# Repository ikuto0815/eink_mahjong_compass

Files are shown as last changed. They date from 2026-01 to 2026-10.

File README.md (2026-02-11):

# E-ink mahjong compass

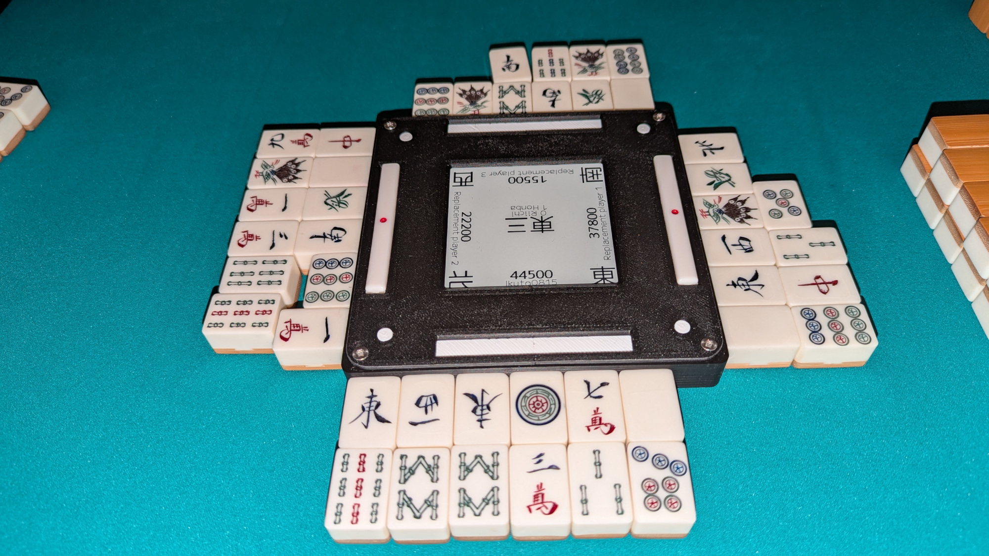
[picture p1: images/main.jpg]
The compass in use


This repo contains all the files neccesary to build a bluetooth controlled digital mahjong compass.

The project is divided into the following main parts:

* [**3d**](3d): the freecad project and stl-files to 3D print the case
* [**android_app**](android_app): the android app used to control the device
* [**firmware**](firmware): firmware for the ESP32 microcontroller inside
* [**pcb**](pcb): design files for the custom PCB

Additional folders:

* [**fontconvert**](fontconvert): tool to convert fonts to C headers, so they can be used in the firmware
* [**hardware**](hardware): datasheets for parts used on the PCB

## PCB

The custom made PCB contains an ESP32-S3-WROOM1 microcontroller to talk to a phone via bluetooth and control the connected periphery.

It has the following components:

* 4.2 inch 400x300 (300x300 visible) E-ink display
* 4 buttons for controlling the device
* 4 indicator LEDs placed below the riichi bet trays of each player
* USB-C port for programming the ESP32 and charging the battery
* TP4056 module to control charging of a single cell LiPo battery via the USB-C port
* (optional and untested MAX17048 fuel gauge controller to determine the battery charge)

The production subfolder contains all the files needed to order the PCBs.
The `eink_mahjong_compass.zip` file contains alle the gerber files needed to order the PCB.
`bom.csv` and `positions.csv` are additionally needed when ordering the PCBs assembled.
The files for assembly will work for JLCPCB, other sites might need a different file format.

Even when ordering with assembly, two parts have to be soldered by hand. Those being the connector
for the E-ink display and the ESP32 module. Adding those would make the assembly service much more expensive.

## How to build

### Requirements

The following things need to be ordered:

* WeAct 4.2 inch Epaper module <https://aliexpress.com/item/1005008461198386.html> (only sold by WeAct Studio Official Store, order the black/white one, the black/red/white variant might not work)
* ESP32-S3-WROOM1-N4 <https://aliexpress.com/item/1005004815894336.html> (there are various vendors, they should all be fine. -N4 is the cheapest variant with 4MB flash and no external RAM. The better variants will probably work as well but won't provide any benefits)
* 2x 4 pin PCB Female Pin Header Socket Connector <https://aliexpress.com/item/1005004122312694.html> for the display connector
* (optional) Ntag 215 NFC tag stickers <https://aliexpress.com/item/1005006387440192.html> stick them on the underside of the lid and write the connect URL to them, so the app auto starts when touching item
* battery, either a 5000mAh 105080 or a 6000mAh 906090 can be used, other formats would need changes to the 3D printed part to hold the battery in place. Example seller <https://aliexpress.com/item/1005004639603622.html> batteries from other sellers will probably work fine as well, but a 2 pin connector is required, not a 3 pin one.
* M3xL4xOD4.2 brass insert nuts. <https://de.aliexpress.com/item/1005006472702418.html> Molded into the case to hold the lid screws
* M3 6mm countersunk screws <https://aliexpress.com/item/33006942612.html>

### Assembly

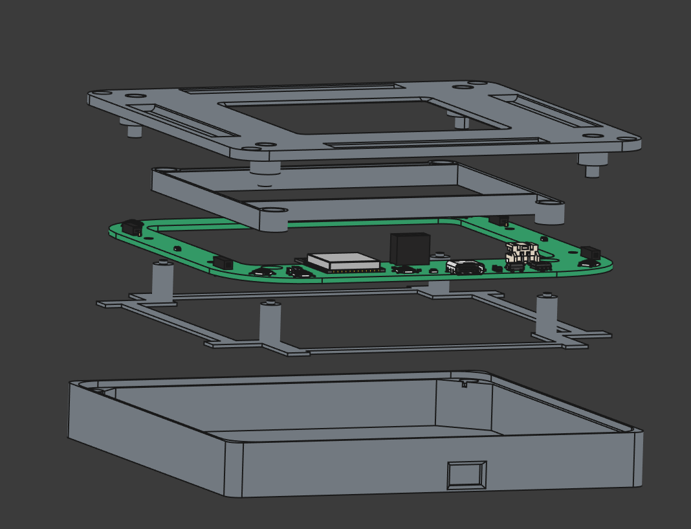
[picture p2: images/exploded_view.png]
exploded view


* 3D print the parts as described in [3d/README](3d/README.md).
* Using a soldering iron push the brass insert nuts into the corners of the case.
* Place the PCB on the printed `display_feet`
* Place the display_feet on top
* Put them into the case
* Place the battery inside and connect it after checking if the polarity of the connector matches that on the PCB.
* Add the screen
* Place the lid on top and screw it down.

### Flashing the firmware

To build and flash the firmware, you need to download and install  [PlatformIO](https://platformio.org/).

Then just connect the compass via USB and run `pio run --target upload` in the firmware directory.

## Other stuff

### Bluetooth interface

The compass currently offers a single BLE service under the UID `bae5e4dd-f2b4-4461-a84c-b7851fb8efd3` with the following characteristics:

#### game state (`bab40271-33ea-48dc-a145-638361f54d2b`)

This characteristic is write only and takes a multi line string that describes the current game state in the following format:

``` text
roundIndex riichiCount honbaCount
windIndex0
score0
name0
windIndex1
score1
name1
windIndex2
score2
name2
windIndex3
score3
name3
```

roundIndex describes the current round of the game (0=E1, 1=E2, 4=S1,...). riichiCount and honbaCount are the number of sticks that would be on the table.

The next lines describe describe the 4 players in the game.
windIndexN is the current wind of each player (0=E, 1=S, 2=W, 3=N).
scoreN and nameN are the current score and name of each player.

The players are drawn on the display in the same order as in the transferred data.

Example:

``` text
1 2 1
0
29000
name0
1
29000
name1
2
38000
name2
3
22000
name3
```

This game is in round east-2, There are two riichi sticks and one honba in the table. Player "name0" is currently east with 29000 points.

#### battery voltage (`bab40271-33ea-48dc-a145-638361f54d2c`)

This characteristic is read-only. It returns the current battery voltage in mV. This can be used for a battery level indicator in the app.

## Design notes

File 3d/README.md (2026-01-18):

This folder contains the 3D models for the case. compass_square.FCStd is the freecad project containing everything.

In the stl folder are stl files for the individual parts that can be directly used for 3D printing.

The files `case.stl`, `display_feet.stl`, `lid.stl` each have to be printed once.

To keep the battery in place either `battery_frame_500mah.stl` (105080 LiPo) or `battery_frame_600mah.stl` (906090 LiPo) can be used. For other battery formats either that part has to be modified or the battery could just be glued to the case.

The parts `button_holder.stl` and `button.stl` each have to be printed 4 times and then glued to the botton of the lid.

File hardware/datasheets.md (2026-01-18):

# Datasheets for used parts

* Battery charging IC TP4056-42-ESOP8
  <https://www.lcsc.com/datasheet/C16581.pdf>
* 3.3V LDO ME6211C33R5G
  <https://www.lcsc.com/datasheet/C235316.pdf>
* USB ESD protection diode SRV05-4-P-T7
  <https://www.lcsc.com/datasheet/C85364.pdf>
* 32.768kHz crystal Q13FC13500004
  <https://www.lcsc.com/datasheet/C32346.pdf>
* P-Channel MOSFET SI2301CDS-T1-GE3
  <https://www.lcsc.com/datasheet/C10487.pdf>
* Schottky diode SS34
  <https://www.lcsc.com/datasheet/C8678.pdf>

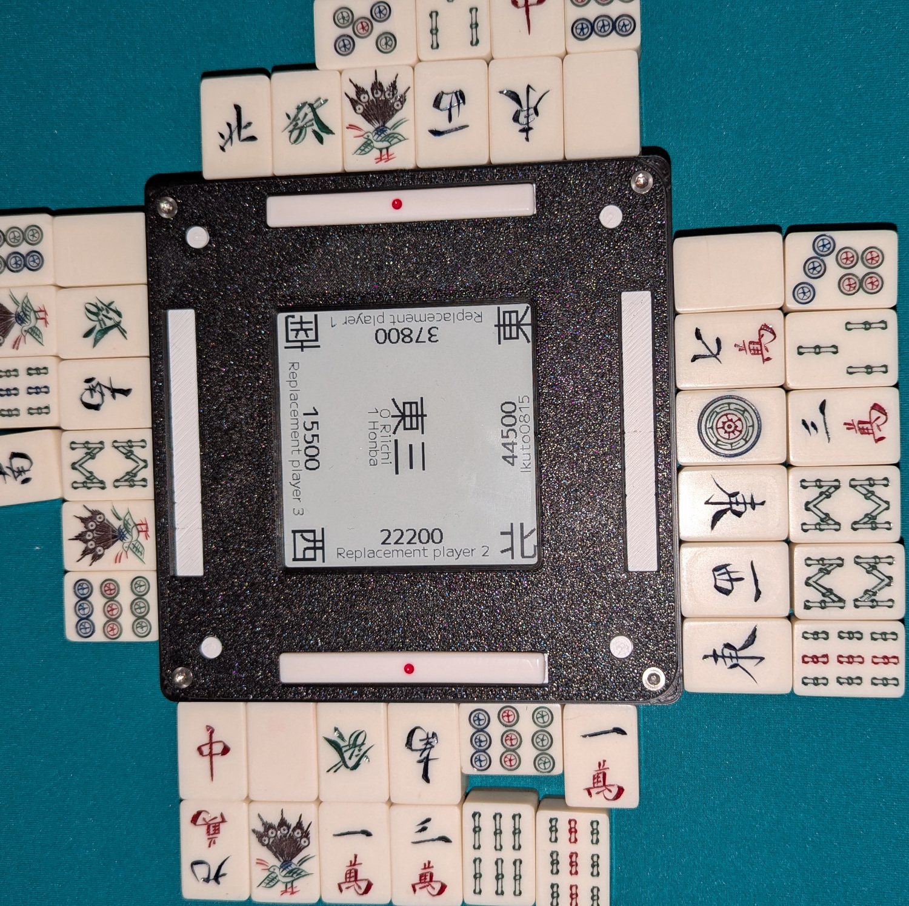
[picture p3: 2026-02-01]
images/top.jpg

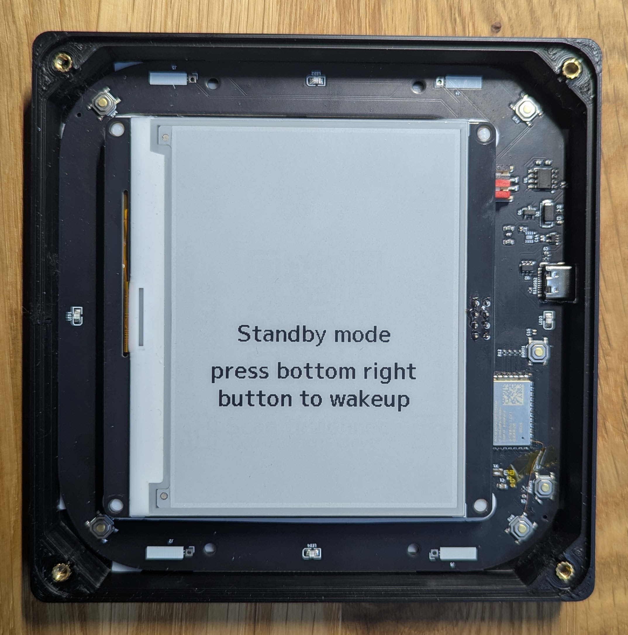
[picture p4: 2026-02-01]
images/inside.jpg

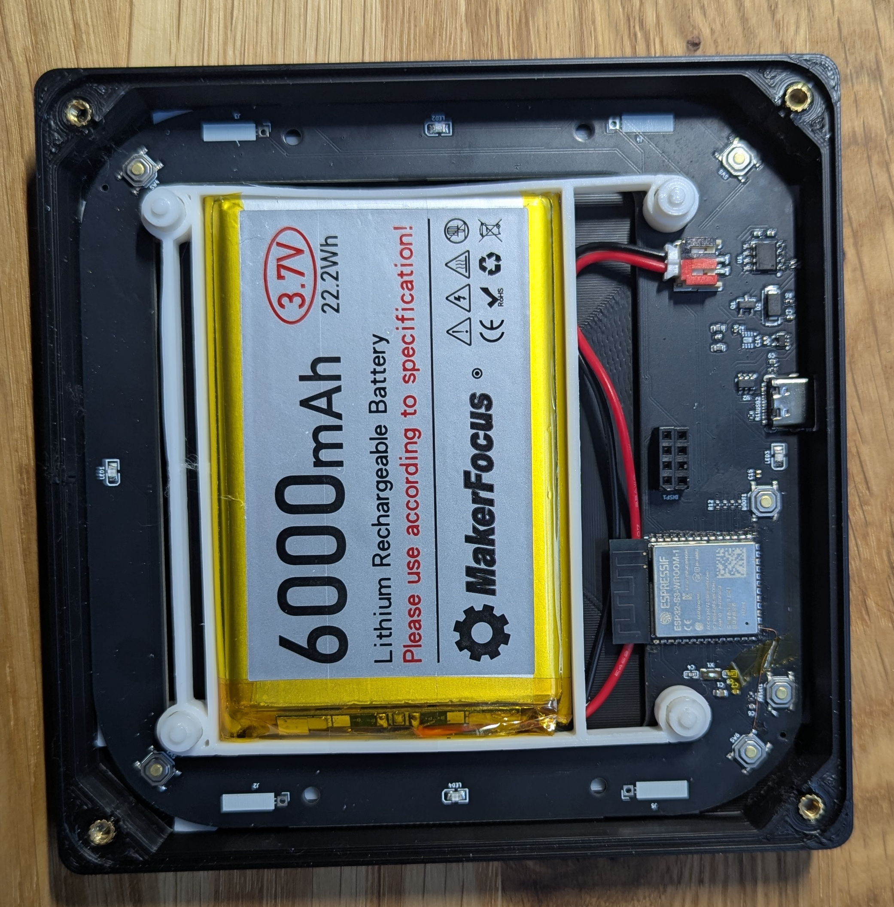
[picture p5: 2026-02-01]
images/inside_2.jpg

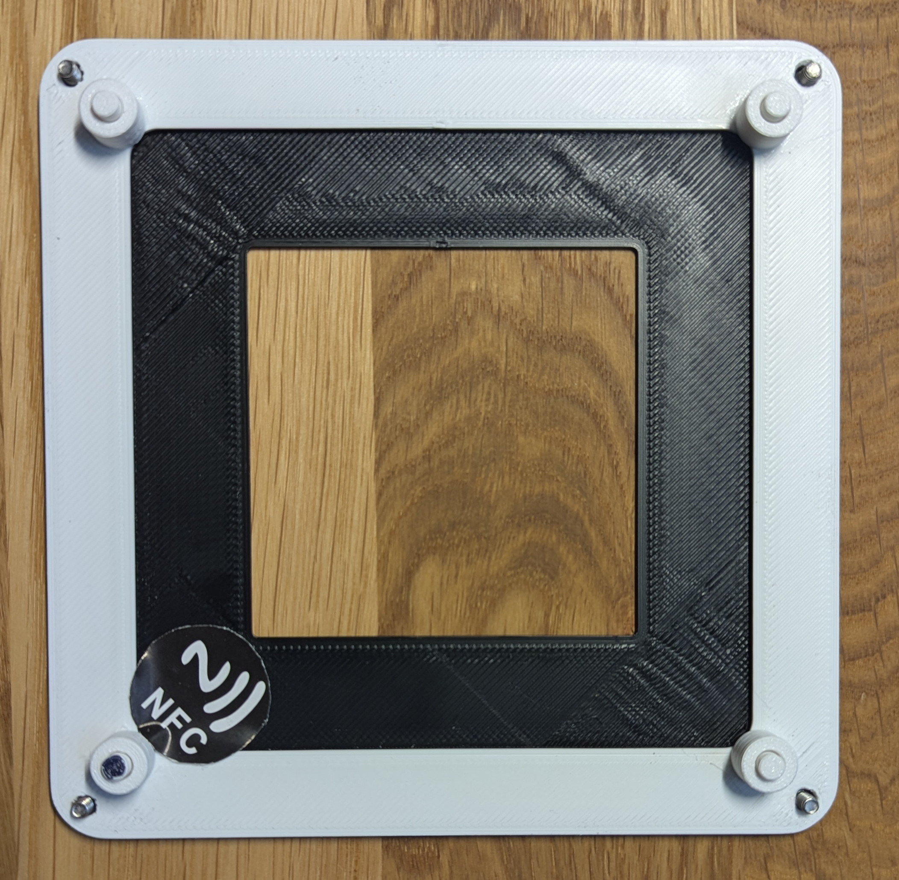
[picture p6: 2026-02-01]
images/lid_underside.jpg

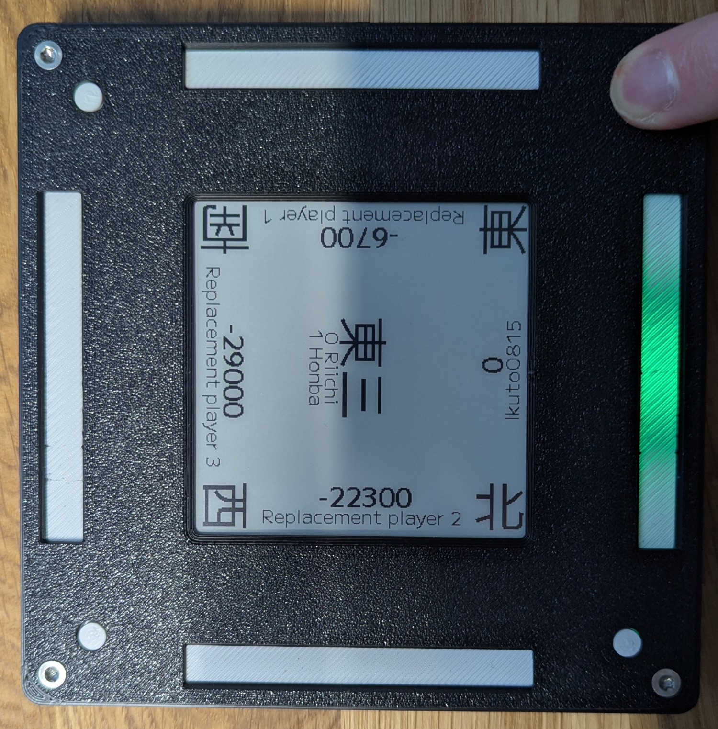
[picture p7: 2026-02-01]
images/button.jpg

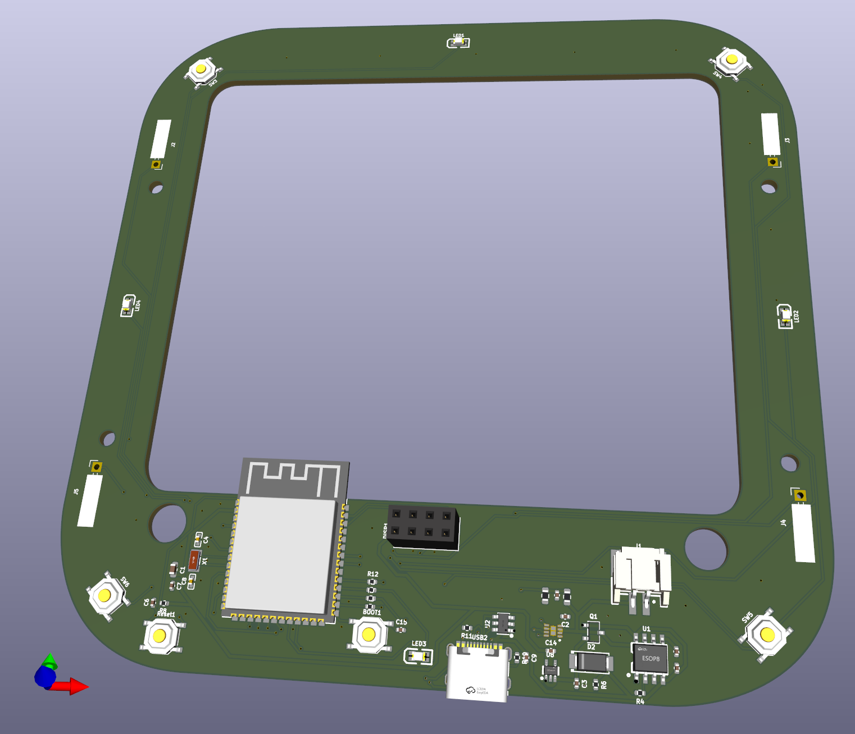
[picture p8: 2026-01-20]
pcb/eink_mahjong_compass.png

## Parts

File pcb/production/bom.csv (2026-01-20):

Designator | Footprint | Quantity | Value | LCSC Part #
BOOT1, RESET1, SW3, SW4, SW5, SW6 | SW-SMD_4P-L5.1-W5.1-P3.70-LS6.5-TL_H1.5 | 6 | C318884
C1 | 0603 | 1 | 22uF
C13, C16 | 0402 | 2 | 10uF
C14, C3 | 0402 | 2 | 1uF
C15, C6 | 0402 | 2 | 1.0uF
C2, C5 | 0402 | 2 | 0.1uF
C4, C8 | C0402 | 2 | 15pF
C7, C9 | 0402 | 2 | 4.7uF
D2 | SMA_L4.3-W2.6-LS5.2-RD | 1 | C8678
DISP1 | PinSocket_2x04_P2.54mm_Vertical | 1 | Conn_02x04_Counter_Clockwise
J1 | CONN-SMD_PH-2AWT | 1 | PH-2AWT | C2763693
LED1, LED2, LED3, LED4 | LED0805-R-RD | 4 | C2297
Q1 | SOT-23-3_L3.0-W1.7-P0.95-LS2.9-BR | 1 | C10487
R1 | 0603 | 1 | 1M
R10, R11 | 0402 | 2 | 5.1k
R12, R5, R7, R9 | 0402 | 4 | 49.9
R2 | 0603 | 1 | 330k
R4 | 0402 | 1 | 2.0k
R6 | 0402 | 1 | 100k
R8 | 0402 | 1 | 10k
U1 | ESOP-8_L4.9-W3.9-P1.27-LS6.0-BL-EP | 1 | C16581
U2 | SOT-23-6_L2.9-W1.6-P0.95-LS2.9-BL | 1 | C85364
U8 | SOT-353_L2.1-W1.3-P0.65-LS2.3-BL | 1 | C235316
USB2 | USB-C_SMD-TYPE-C-31-M-12 | 1 | C2927038
X1 | FC-135R_L3.2-W1.5 | 1 | C32346

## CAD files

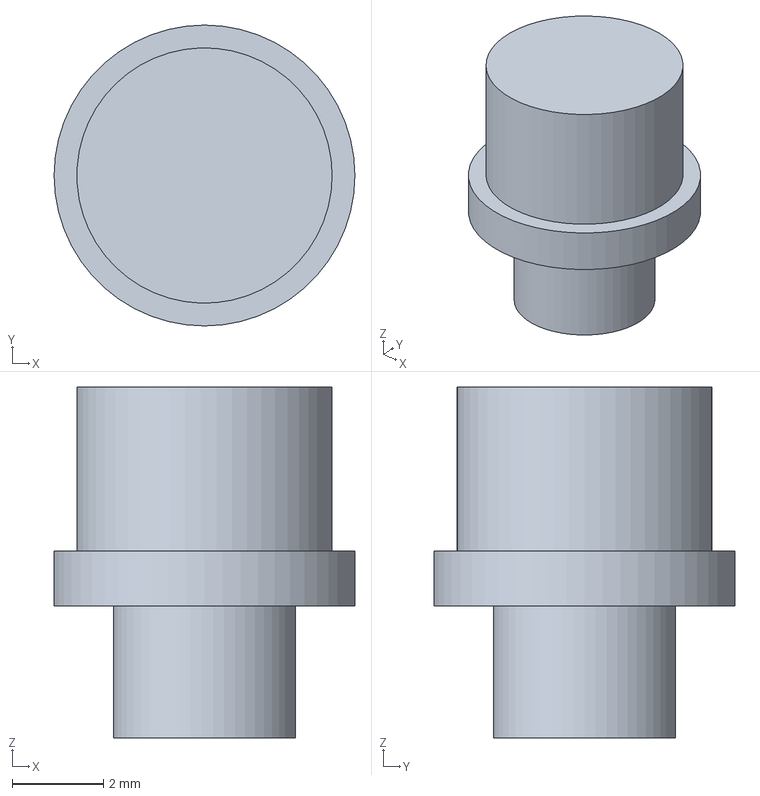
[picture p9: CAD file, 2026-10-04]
3d/compass_square.FCStd
6.60 x 6.60 x 7.70 mm

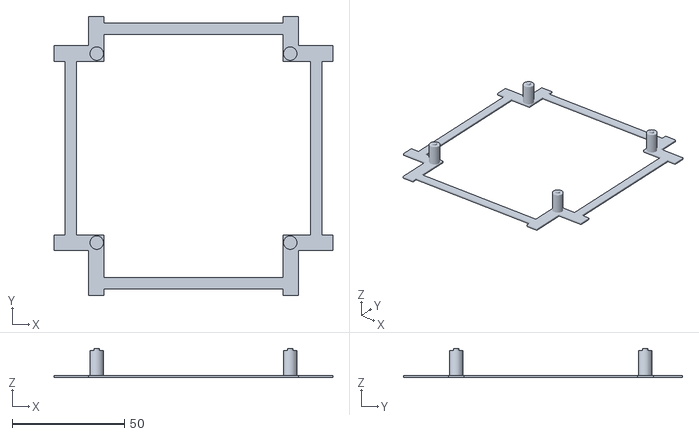
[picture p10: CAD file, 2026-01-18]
3d/stl/display_feet.stl
124.3 x 124.3 x 13.0

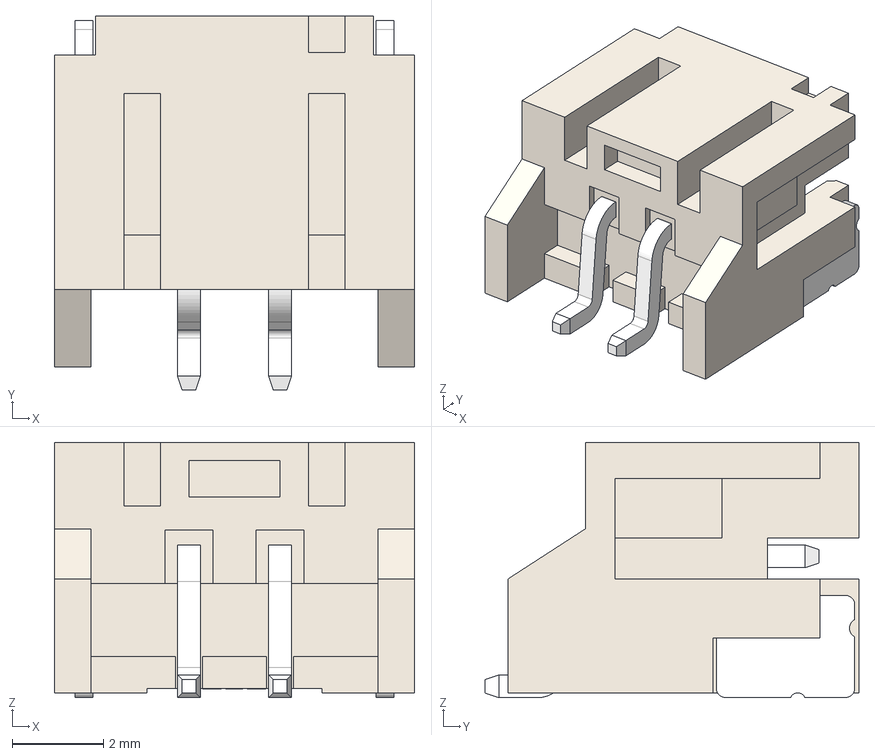
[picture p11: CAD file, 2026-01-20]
pcb/EASYEDA_MODELS/CONN-SMD_PH-2AWT.step
7.90 x 8.20 x 5.61 mm

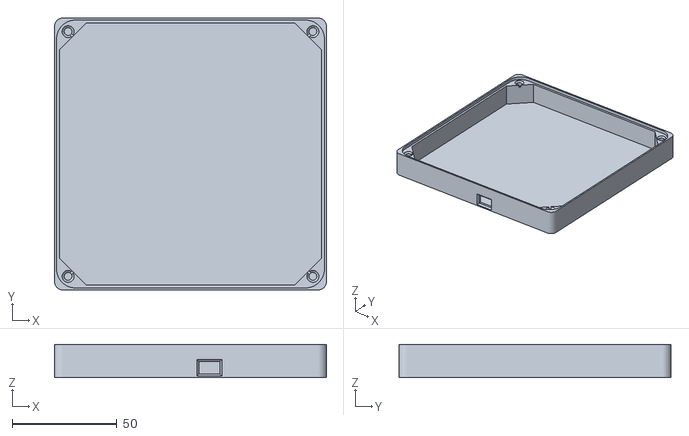
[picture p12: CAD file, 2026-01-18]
3d/stl/case.stl
130.0 x 130.0 x 16.0

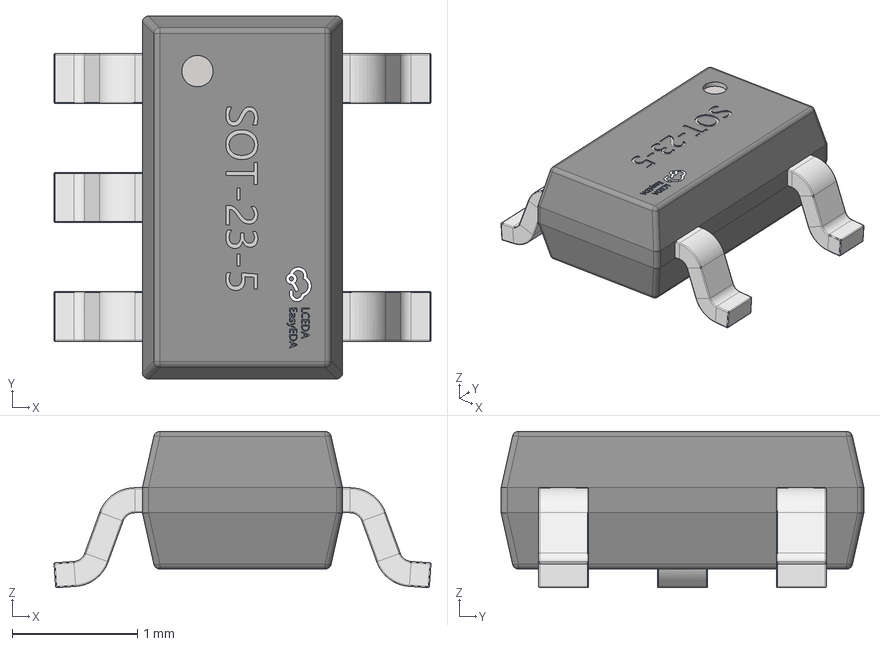
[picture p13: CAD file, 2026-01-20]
pcb/EASYEDA_MODELS/SOT-23-5_L2.9-W1.6-H1.1-LS2.8-P0.95.step
3.01 x 2.90 x 1.25 mm

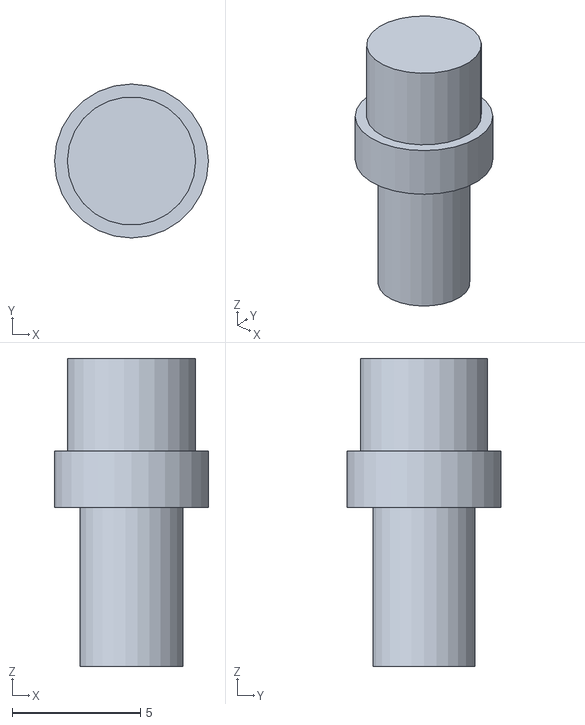
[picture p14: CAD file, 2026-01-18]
3d/stl/button.stl
6.00 x 6.00 x 12.0

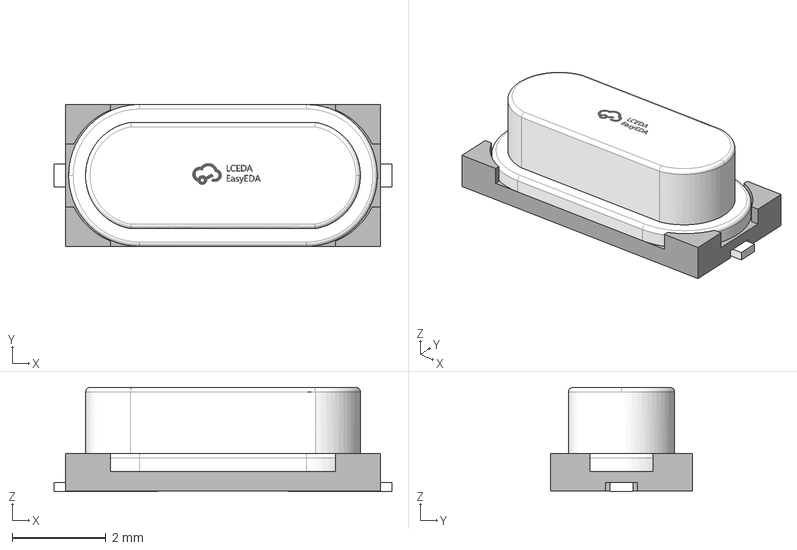
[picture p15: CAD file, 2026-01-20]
pcb/EASYEDA_MODELS/OSC-SMD_L7.0-W3.2-LS7.5.step
7.21 x 3.03 x 2.22 mm

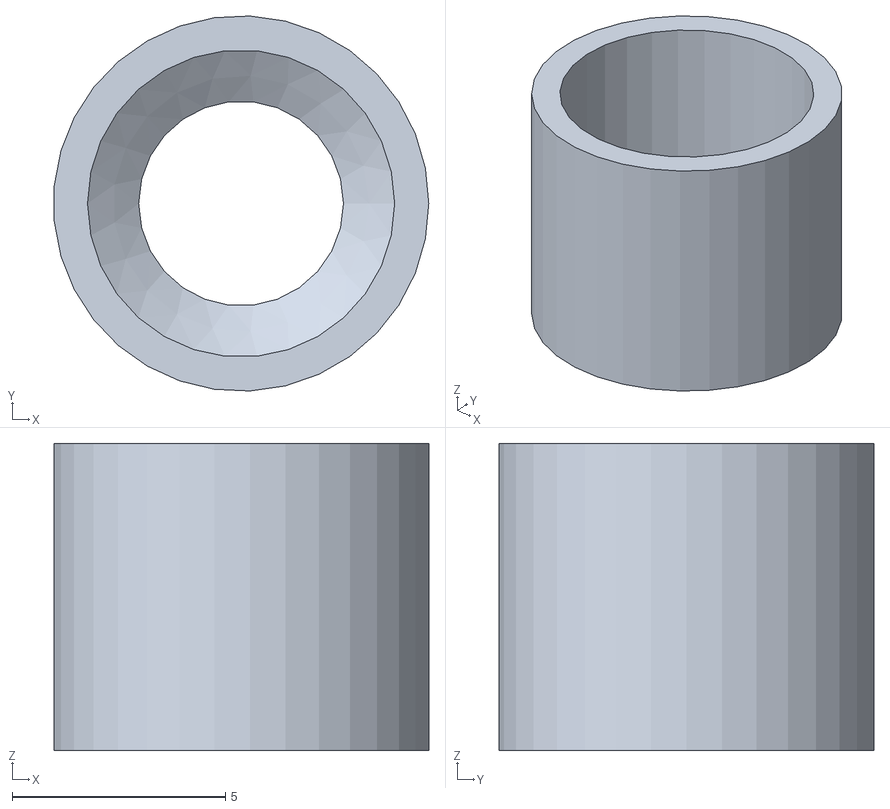
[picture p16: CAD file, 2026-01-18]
3d/stl/button_holder.stl
8.78 x 8.79 x 7.20

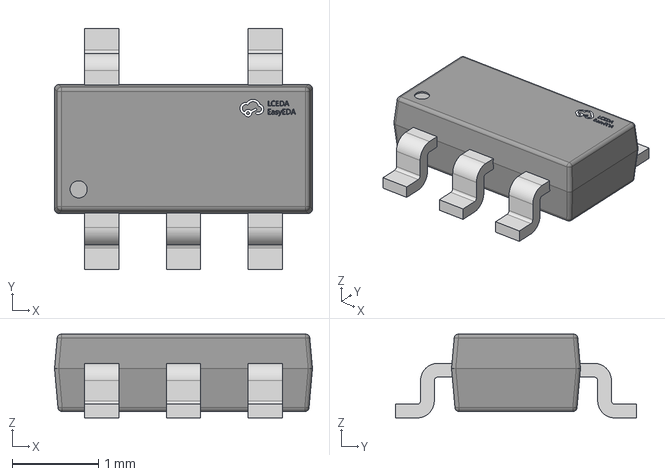
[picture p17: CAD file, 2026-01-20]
pcb/EASYEDA_MODELS/SOT-23-5_L3.0-W1.5-P0.95-LS2.8-BL.step
3.00 x 2.80 x 0.976 mm

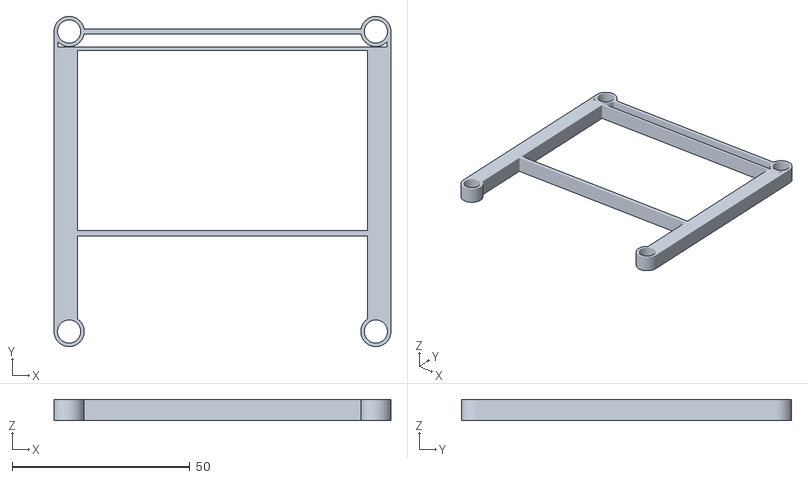
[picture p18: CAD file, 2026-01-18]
3d/stl/battery_frame_500mah.stl
94.7 x 92.8 x 6.00

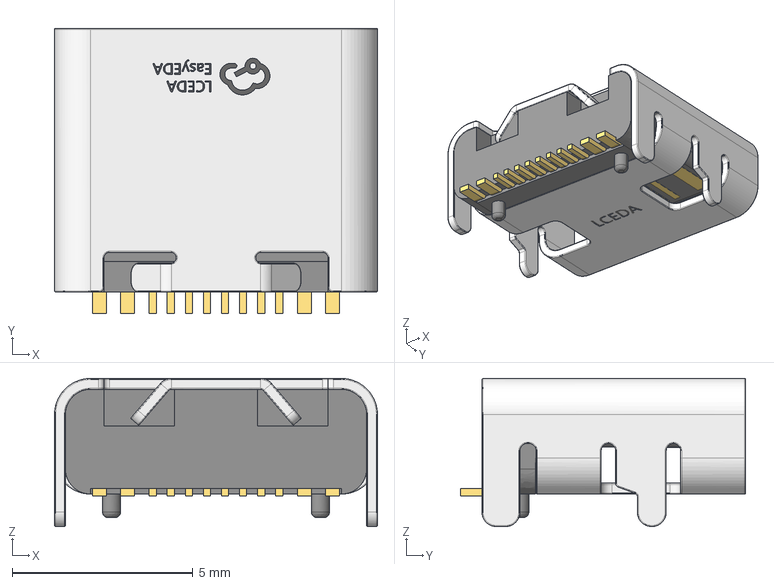
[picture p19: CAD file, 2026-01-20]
pcb/EASYEDA_MODELS/USB-C_SMD-TYPE-C-31-M-12.step
8.94 x 7.90 x 4.10 mm

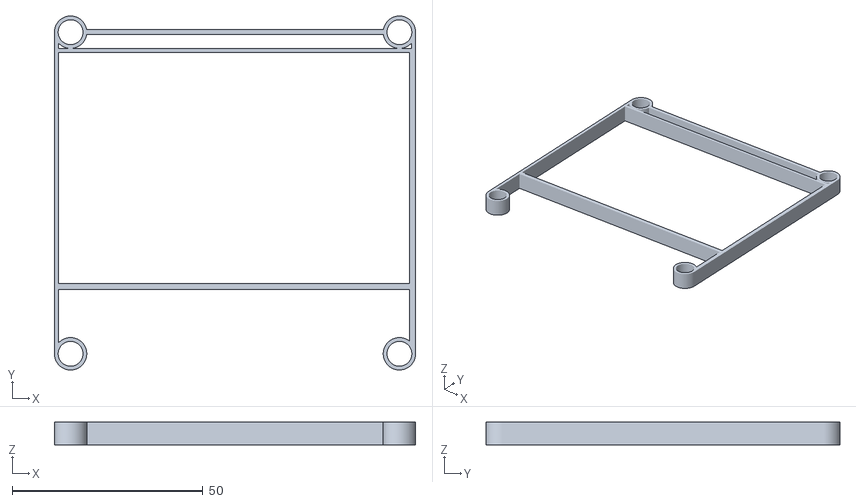
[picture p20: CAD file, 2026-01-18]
3d/stl/battery_frame_600mah.stl
94.7 x 92.8 x 6.00

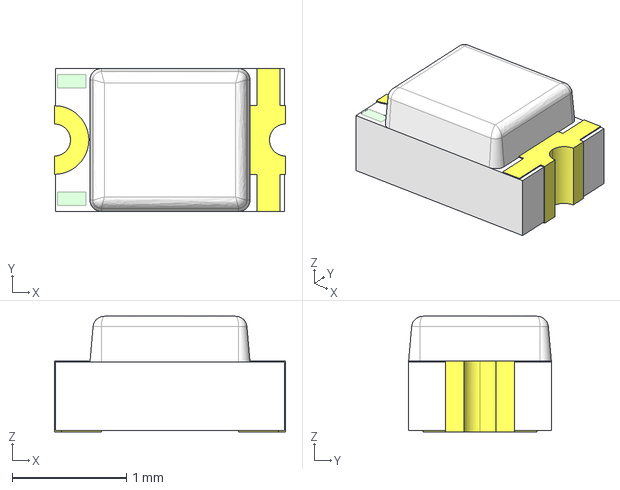
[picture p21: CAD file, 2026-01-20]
pcb/EASYEDA_MODELS/LED0805-RD.step
2.02 x 1.25 x 1.01 mm

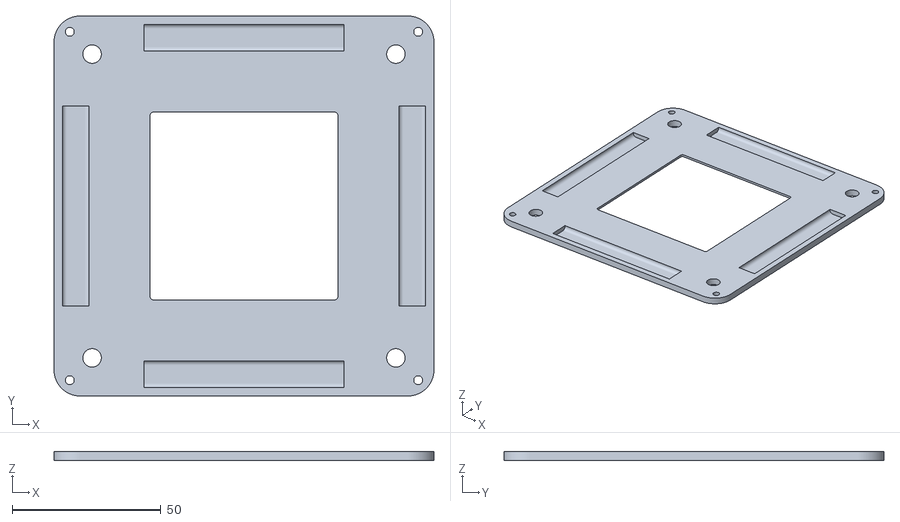
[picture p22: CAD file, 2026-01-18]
3d/stl/lid.stl
127.6 x 127.6 x 3.00

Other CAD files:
pcb/EASYEDA_MODELS/FC-135R_L3.2-W1.5.step
pcb/EASYEDA_MODELS/WIFIM-SMD_ESP32-S3-WROOM-1-N8.step
pcb/EASYEDA_MODELS/SOT-23-3L_L2.9-W1.6-H1.1-LS2.8-P0.95.step
pcb/EASYEDA_MODELS/SMA_L4.3-W2.6-LS5.1-RD.step
pcb/EASYEDA_MODELS/C0402_L1.0-W0.5-H0.5.step
pcb/EASYEDA_MODELS/ESOP-8_L4.9-W3.9-H1.6-LS6.0-P1.27.step
pcb/EASYEDA_MODELS/SOT-23-5_L2.9-W1.6-P0.95-LS2.8-BR.step
pcb/EASYEDA_MODELS/SOT-23-6_L2.9-W1.6-P0.95-LS2.9-BL.step
pcb/EASYEDA_MODELS/SOT-353-5P_L2.0-W1.3-H1.1-LS2.0-P0.65.step
pcb/EASYEDA_MODELS/SOT-89-3_L4.3-W2.5-H1.6-LS4.1-P1.50.step
pcb/EASYEDA_MODELS/SW-SMD_4P-L5.1-W5.1-P3.70-LS6.5-TL_H1.5.step
pcb/EASYEDA_MODELS/TSOT-23-5_L2.9-W1.6-H1.00-LS2.8-P0.95.step
pcb/EASYEDA_MODELS/TYPE-C-SMD_6P-L8.9-W6.8-H3.2-P1.00.step
pcb/EASYEDA_MODELS/USB-C-SMD_HYCW498-USBC16-735B.step
pcb/EASYEDA_MODELS/WIRELM-SMD_ESP32-S3-WROOM-1.step
pcb/EASYEDA_MODELS/WIRELM-SMD_ESP32-S3-WROOM-1U.step

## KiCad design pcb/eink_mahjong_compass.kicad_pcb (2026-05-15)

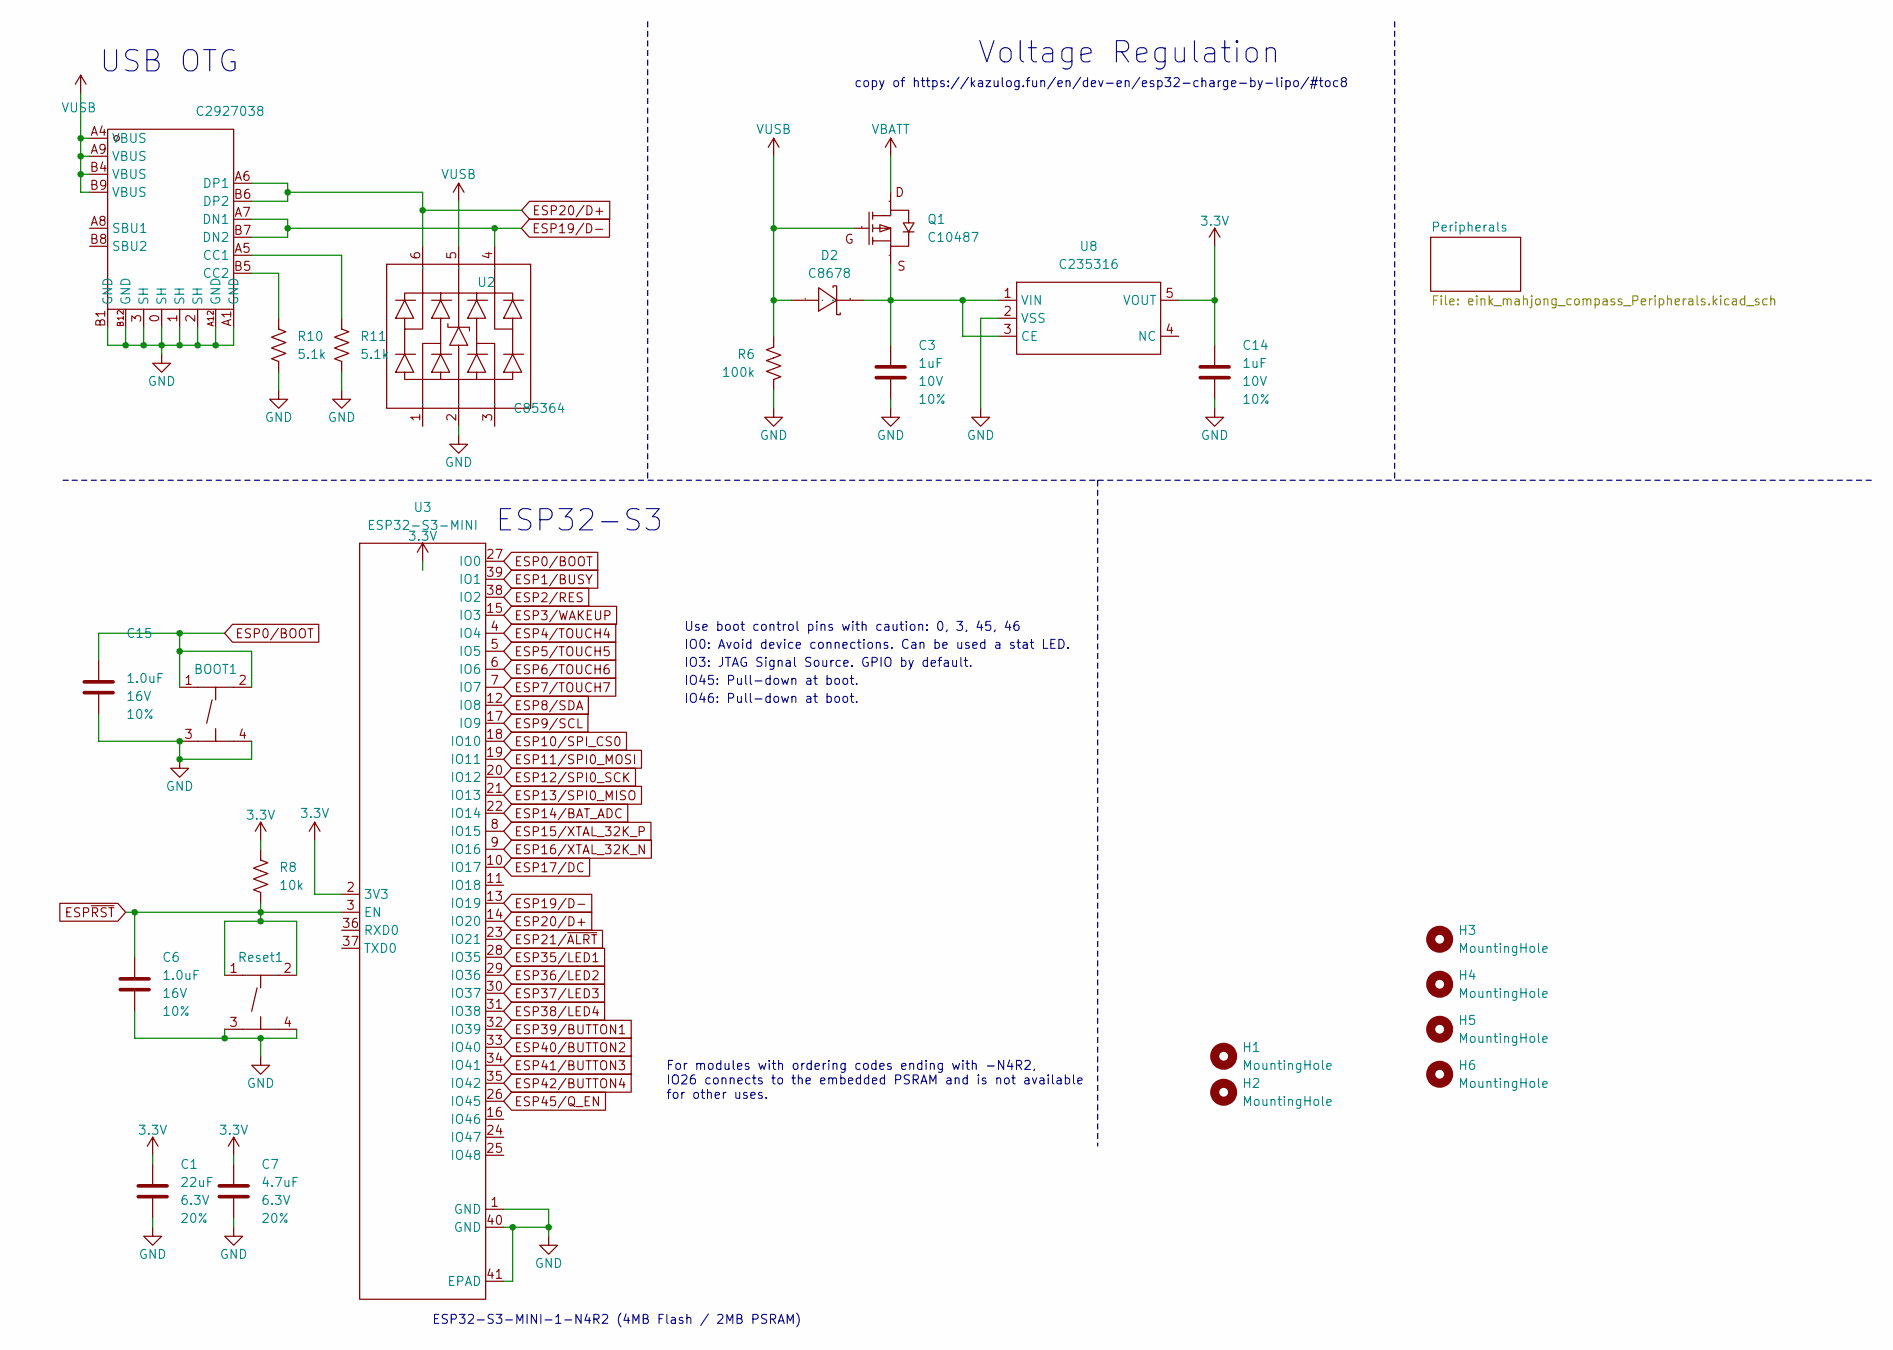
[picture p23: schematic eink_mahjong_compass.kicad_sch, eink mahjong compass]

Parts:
BOOT1: C318884; SW-SMD_4P-L5.1-W5.1-P3.70-LS6.5-TL_H1.5; Manufacturer Part TS-1187A-B-A-B; LCSC Part Name 5.1*5.1*1.5mm 立贴 轻触开关
C1: 22uF; C_0603_1608Metric; Voltage 6.3V; Tolerance 20%
C3, C14: 1uF; C_0402_1005Metric; Voltage 10V; Tolerance 10%
C6, C15: 1.0uF; C_0402_1005Metric; Voltage 16V; Tolerance 10%
C7: 4.7uF; C_0402_1005Metric; Voltage 6.3V; Tolerance 20%
D2: C8678; SMA_L4.3-W2.6-LS5.2-RD; Manufacturer Part SS34; LCSC Part Name 电压:40V 电流:3A
H1, H2: MountingHole; MountingHole_6.4mm_M6_DIN965
H3, H4, H5, H6: MountingHole; MountingHole_2.7mm_M2.5_ISO14580
Q1: C10487; SOT-23-3_L3.0-W1.7-P0.95-LS2.9-BR; Manufacturer Part SI2301CDS-T1-GE3; LCSC Part Name 1个P沟道 耐压:20V 电流:3.1A
R6: 100k; R_0402_1005Metric
R8: 10k; R_0402_1005Metric
R10, R11: 5.1k; R_0402_1005Metric
Reset1: C318884; SW-SMD_4P-L5.1-W5.1-P3.70-LS6.5-TL_H1.5; Manufacturer Part TS-1187A-B-A-B; LCSC Part Name 5.1*5.1*1.5mm 立贴 轻触开关
U2: C85364; SOT-23-6_L2.9-W1.6-P0.95-LS2.9-BL; Manufacturer Part C85364; LCSC Part Name 丝印:V05 单向ESD 5V截止 峰值浪涌电流：4A@8/20us
U3: ESP32-S3-MINI; WIRELM-SMD_ESP32-S3-WROOM-1; Manufacturer Part ESP32-S3-WROOM-1; LCSC Part Name ESP32-S3-WROOM-1
U8: C235316; SOT-353_L2.1-W1.3-P0.65-LS2.3-BL; Manufacturer Part ME6211C33R5G; LCSC Part Name 输入6.5V 输出3.3V 300mA
USB2: C2927038; USB-C_SMD-TYPE-C-31-M-12; Manufacturer Part USB-TYPE-C-018; LCSC Part Name Type-C 母 卧贴

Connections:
3.3V: C1.2, C7.1, C14.1, R8.1, U3.2 (3V3), U8.5 (VOUT); also elsewhere on the board
ESP0/BOOT: BOOT1.1 (A), BOOT1.2 (B), C15.1, U3.27 (IO0)
ESP1/BUSY: U3.39 (IO1); also elsewhere on the board
ESP2/RES: U3.38 (IO2); also elsewhere on the board
ESP3/WAKEUP: U3.15 (IO3), U3.35 (IO42); also elsewhere on the board
ESP4/TOUCH4: U3.4 (IO4); also elsewhere on the board
ESP5/TOUCH5: U3.5 (IO5); also elsewhere on the board
ESP6/TOUCH6: U3.6 (IO6); also elsewhere on the board
ESP7/TOUCH7: U3.7 (IO7); also elsewhere on the board
ESP8/SDA: U3.12 (IO8); also elsewhere on the board
ESP9/SCL: U3.17 (IO9); also elsewhere on the board
ESP10/SPI_CS0: U3.18 (IO10); also elsewhere on the board
ESP11/SPI0_MOSI: U3.19 (IO11); also elsewhere on the board
ESP12/SPI0_SCK: U3.20 (IO12); also elsewhere on the board
ESP13/SPI0_MISO: U3.21 (IO13)
ESP14/BAT_ADC: U3.22 (IO14); also elsewhere on the board
ESP15/XTAL_32K_P: U3.8 (IO15); also elsewhere on the board
ESP16/XTAL_32K_N: U3.9 (IO16); also elsewhere on the board
ESP17/DC: U3.10 (IO17); also elsewhere on the board
ESP19/D-: U2.4 (I/O), U3.13 (IO19), USB2.A7 (DN1), USB2.B7 (DN2)
ESP20/D+: U2.6 (I/O), U3.14 (IO20), USB2.A6 (DP1), USB2.B6 (DP2)
ESP21/~ALRT: U3.23 (IO21); also elsewhere on the board
ESP35/LED1: U3.28 (IO35); also elsewhere on the board
ESP36/LED2: U3.29 (IO36); also elsewhere on the board
ESP37/LED3: U3.30 (IO37); also elsewhere on the board
ESP38/LED4: U3.31 (IO38); also elsewhere on the board
ESP39/BUTTON1: U3.32 (IO39); also elsewhere on the board
ESP40/BUTTON2: U3.33 (IO40); also elsewhere on the board
ESP41/BUTTON3: U3.34 (IO41); also elsewhere on the board
ESP45/Q_EN: U3.26 (IO45)
ESP~RST: C6.1, R8.2, Reset1.1 (A), Reset1.2 (B), U3.3 (EN)
GND: BOOT1.3 (C), BOOT1.4 (D), C1.1, C3.2, C6.2, C7.2, C14.2, C15.2, R6.2, R10.1, R11.2, Reset1.3 (C), Reset1.4 (D), U2.2 (VN), U3.1 (GND), U3.40 (GND), U3.41 (EPAD), U8.2 (VSS), USB2.0 (SH), USB2.1 (SH), USB2.2 (SH), USB2.3 (SH), USB2.A1 (GND), USB2.A12 (GND), USB2.B1 (GND), USB2.B12 (GND); also elsewhere on the board
unnamed: C3.1, D2.1 (K), Q1.2 (S), U8.1 (VIN), U8.3 (CE)
unnamed: R11.1, USB2.A5 (CC1)
unnamed: R10.2, USB2.B5 (CC2)
VBATT: Q1.3 (D); also elsewhere on the board
VUSB: D2.2 (A), Q1.1 (G), R6.1, U2.5 (VP), USB2.A4 (VBUS), USB2.A9 (VBUS), USB2.B4 (VBUS), USB2.B9 (VBUS); also elsewhere on the board

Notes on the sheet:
ESP32-S3
copy of https://kazulog.fun/en/dev-en/esp32-charge-by-lipo/#toc8
IO46: Pull-down at boot.
For modules with ordering codes ending with -N4R2, IO26 connects to the embedded PSRAM and is not available for other uses.
IO45: Pull-down at boot.
IO3: JTAG Signal Source. GPIO by default.
USB OTG
ESP32-S3-MINI-1-N4R2 (4MB Flash / 2MB PSRAM)
Voltage Regulation
IO0: Avoid device connections. Can be used a stat LED.
Use boot control pins with caution: 0, 3, 45, 46

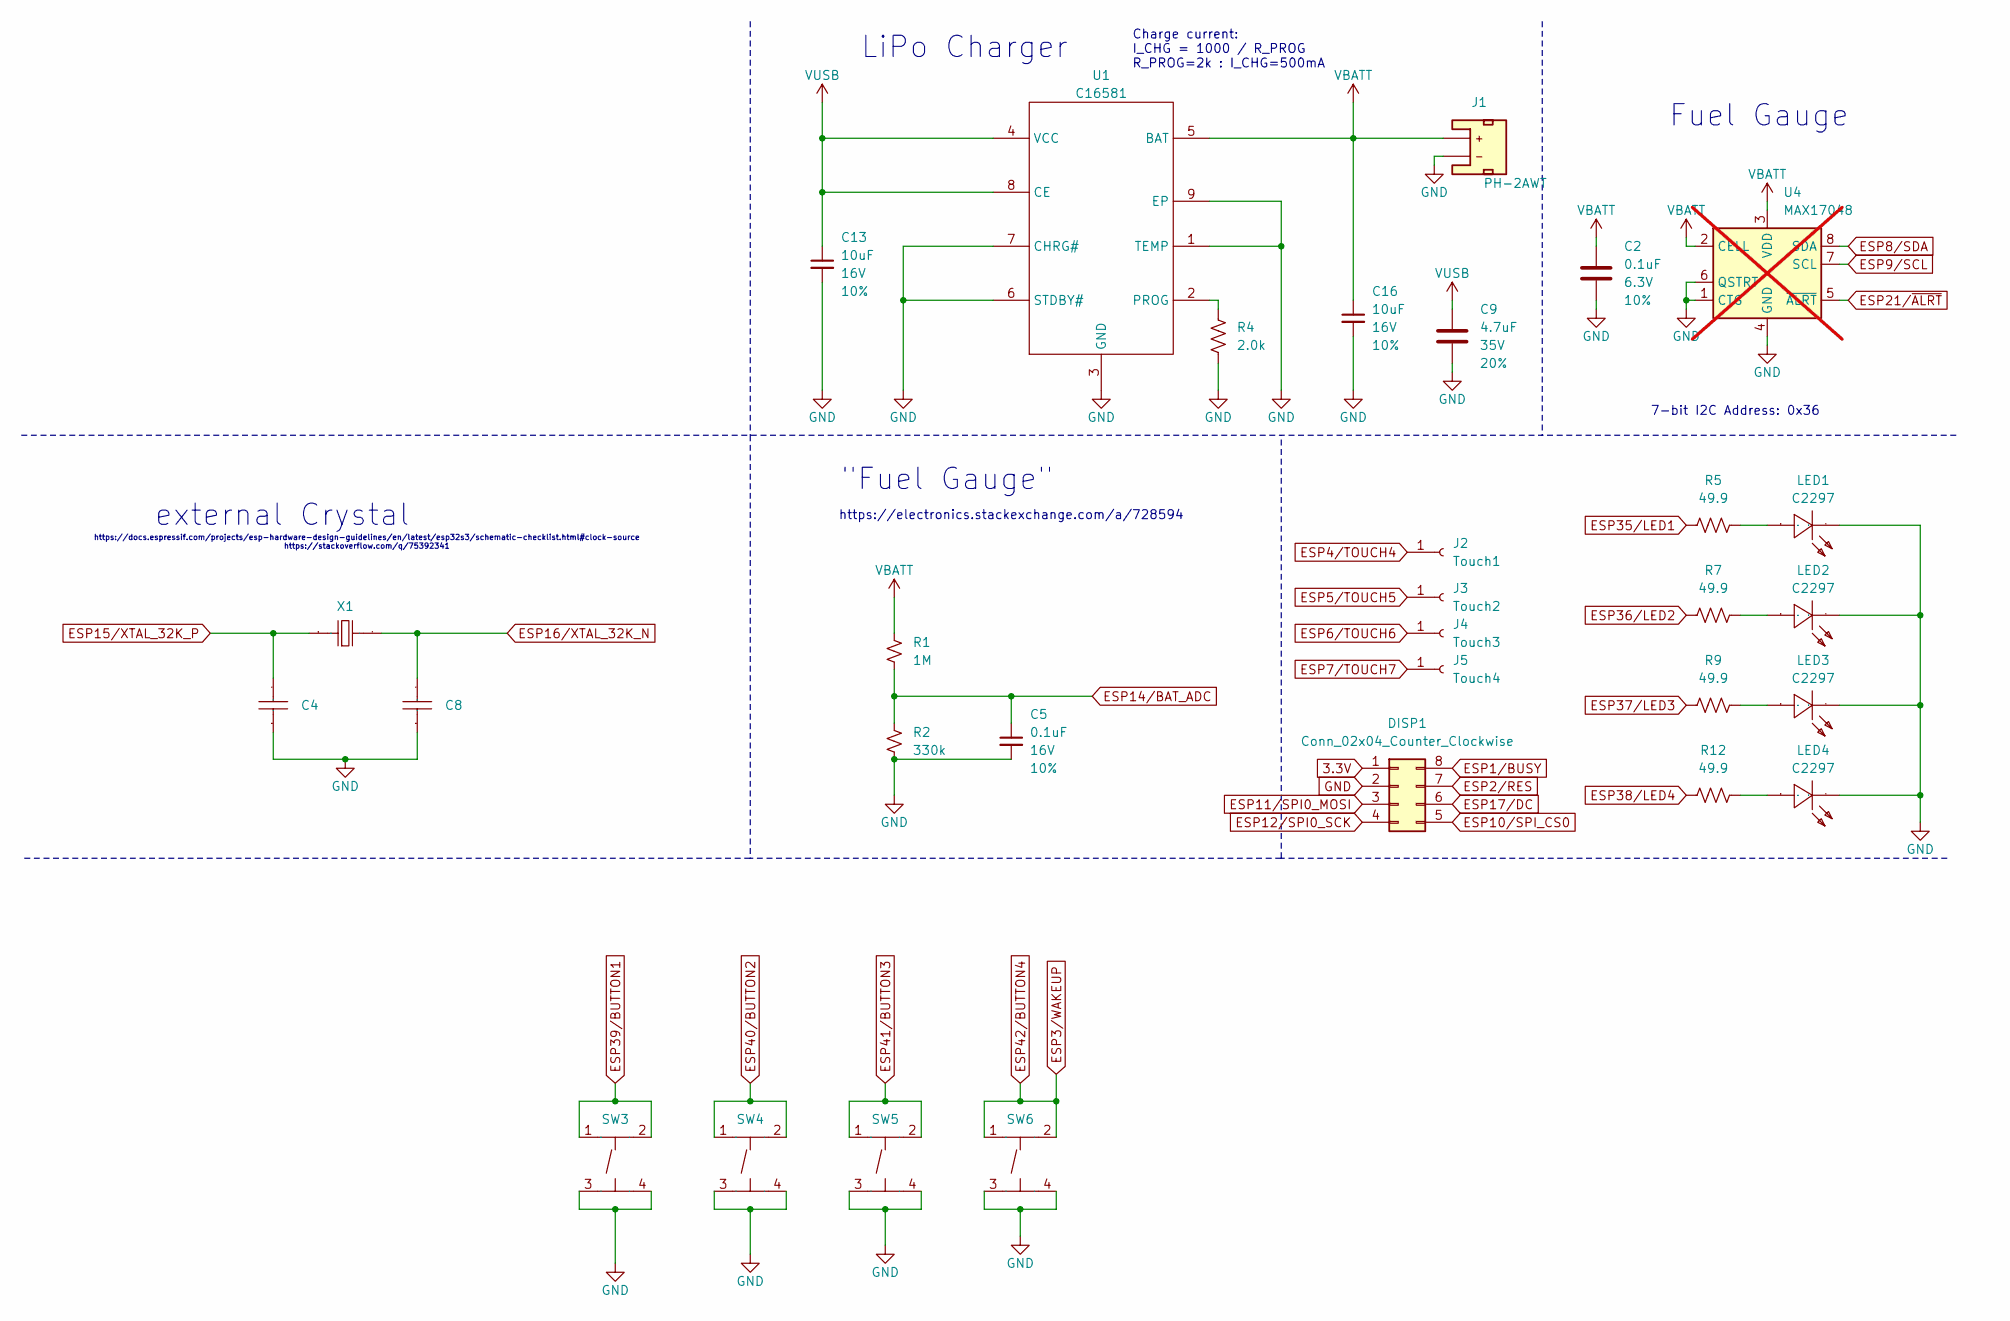
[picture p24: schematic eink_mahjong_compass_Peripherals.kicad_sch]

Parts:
C2: 0.1uF; C_0402_1005Metric; Voltage 6.3V; Tolerance 10%
C4, C8: 15pF; C0402; Manufacturer Part 0402CG4R0C500NT; LCSC Part Name ±0.25pF 4pF 50V
C5: 0.1uF; C_0402_1005Metric; Voltage 16V; Tolerance 10%
C9: 4.7uF; C_0402_1005Metric; Voltage 35V; Tolerance 20%
C13, C16: 10uF; C_0402_1005Metric; Voltage 16V; Tolerance 10%
DISP1: Conn_02x04_Counter_Clockwise; PinSocket_2x04_P2.54mm_Vertical
J1: PH-2AWT; CONN-SMD_PH-2AWT; JLC C2763693
J2: Touch1; PinSocket_1x01_P2.54mm_Horizontal
J3: Touch2; PinSocket_1x01_P2.54mm_Horizontal
J4: Touch3; PinSocket_1x01_P2.54mm_Horizontal
J5: Touch4; PinSocket_1x01_P2.54mm_Horizontal
LED1, LED2, LED3, LED4: C2297; LED0805-R-RD; Manufacturer Part KT-0805G; LCSC Part Name 0805 翠绿 高亮
R1: 1M; R_0603_1608Metric
R2: 330k; R_0603_1608Metric
R4: 2.0k; R_0402_1005Metric
R5, R7, R9, R12: 49.9; R_0402_1005Metric
SW3, SW4, SW5, SW6: C318884; SW-SMD_4P-L5.1-W5.1-P3.70-LS6.5-TL_H1.5; Manufacturer Part TS-1187A-B-A-B; LCSC Part Name 5.1*5.1*1.5mm 立贴 轻触开关
U1: C16581; ESOP-8_L4.9-W3.9-P1.27-LS6.0-BL-EP; Manufacturer Part TP4056-42-ESOP8; LCSC Part Name 单节锂离子电池线性充电器
U4: MAX17048; DFN-8; not fitted
X1: C32346; FC-135R_L3.2-W1.5; Manufacturer Part Q13FC13500004; LCSC Part Name 32.768kHz ±20ppm 12.5pF

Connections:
3.3V: DISP1.1; also elsewhere on the board
ESP1/BUSY: DISP1.8; also elsewhere on the board
ESP2/RES: DISP1.7; also elsewhere on the board
ESP3/WAKEUP: SW6.1 (A), SW6.2 (B); also elsewhere on the board
ESP4/TOUCH4: J2.1 (Pin_1_1); also elsewhere on the board
ESP5/TOUCH5: J3.1 (Pin_1_1); also elsewhere on the board
ESP6/TOUCH6: J4.1 (Pin_1_1); also elsewhere on the board
ESP7/TOUCH7: J5.1 (Pin_1_1); also elsewhere on the board
ESP8/SDA: U4.8 (SDA); also elsewhere on the board
ESP9/SCL: U4.7 (SCL); also elsewhere on the board
ESP10/SPI_CS0: DISP1.5; also elsewhere on the board
ESP11/SPI0_MOSI: DISP1.3; also elsewhere on the board
ESP12/SPI0_SCK: DISP1.4; also elsewhere on the board
ESP14/BAT_ADC: C5.1, R1.1, R2.2; also elsewhere on the board
ESP15/XTAL_32K_P: C4.2, X1.1; also elsewhere on the board
ESP16/XTAL_32K_N: C8.2, X1.2; also elsewhere on the board
ESP17/DC: DISP1.6; also elsewhere on the board
ESP21/~ALRT: U4.5 (~ALRT); also elsewhere on the board
ESP35/LED1: R5.1; also elsewhere on the board
ESP36/LED2: R7.1; also elsewhere on the board
ESP37/LED3: R9.1; also elsewhere on the board
ESP38/LED4: R12.1; also elsewhere on the board
ESP39/BUTTON1: SW3.1 (A), SW3.2 (B); also elsewhere on the board
ESP40/BUTTON2: SW4.1 (A), SW4.2 (B); also elsewhere on the board
ESP41/BUTTON3: SW5.1 (A), SW5.2 (B); also elsewhere on the board
GND: C2.2, C4.1, C5.2, C8.1, C9.2, C13.2, C16.2, DISP1.2, J1.1 (-), LED1.2 (K), LED2.2 (K), LED3.2 (K), LED4.2 (K), R2.1, R4.2, SW3.3 (C), SW3.4 (D), SW4.3 (C), SW4.4 (D), SW5.3 (C), SW5.4 (D), SW6.3 (C), SW6.4 (D), U1.1 (TEMP), U1.3 (GND), U1.6 (STDBY#), U1.7 (CHRG#), U1.9 (EP), U4.1 (CTG), U4.4 (GND), U4.6 (QSTRT), U4.9 (GND); also elsewhere on the board
unnamed: LED1.1 (A), R5.2
unnamed: LED2.1 (A), R7.2
unnamed: LED3.1 (A), R9.2
unnamed: LED4.1 (A), R12.2
unnamed: R4.1, U1.2 (PROG)
VBATT: C2.1, C16.1, J1.2 (+), R1.2, U1.5 (BAT), U4.2 (CELL), U4.3 (VDD); also elsewhere on the board
VUSB: C9.1, C13.1, U1.4 (VCC), U1.8 (CE); also elsewhere on the board

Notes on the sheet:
https://docs.espressif.com/projects/esp-hardware-design-guidelines/en/latest/esp32s3/schematic-checklist.html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 https://stackoverflow.com/q/75392341
LiPo Charger
Charge current: I_CHG = 1000 / R_PROG R_PROG=2k : I_CHG=500mA
Fuel Gauge
external Crystal
https://electronics.stackexchange.com/a/728594
"Fuel Gauge"
7-bit I2C Address: 0x36

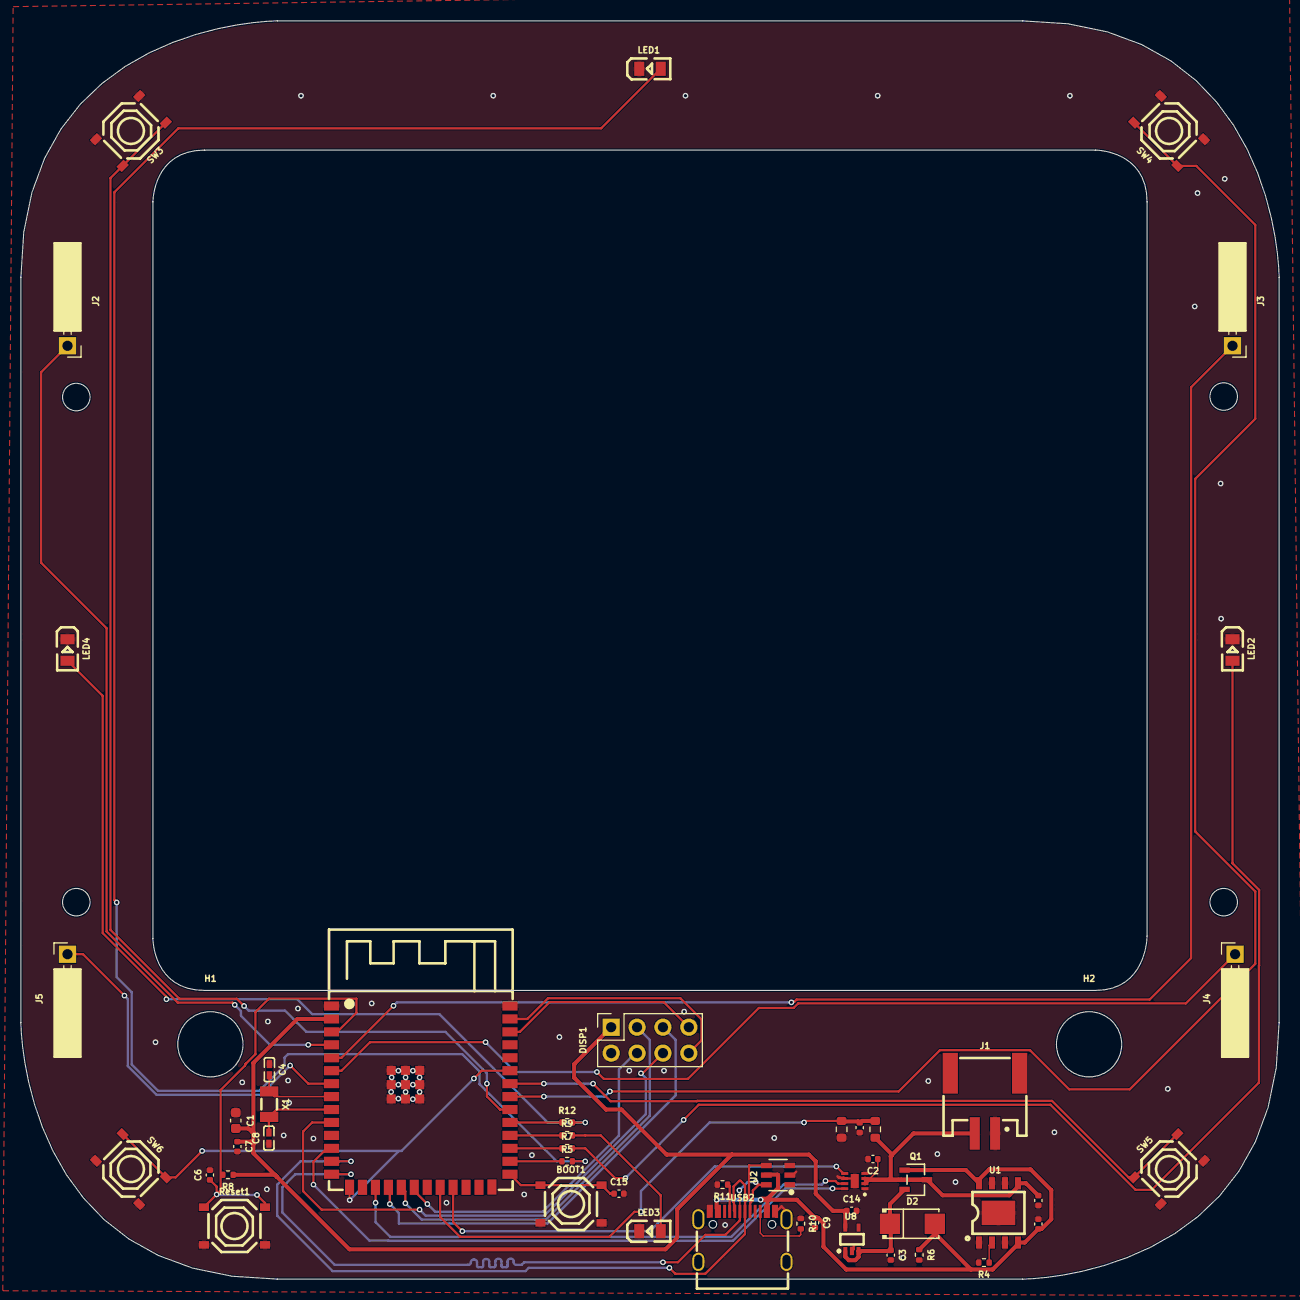
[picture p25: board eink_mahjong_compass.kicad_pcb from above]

Board: 2 copper layers, 123.4 x 123.4 mm, 55 parts (0 on the bottom side), 40 nets.

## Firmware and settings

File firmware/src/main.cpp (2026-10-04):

#include <Arduino.h>

#include "ble.h"
#include "display.h"
#include "io.h"
#include "game_state.h"

#include "esp_pm.h"

static void configure_light_sleep(bool enable)
{
	esp_pm_config_t pm_config = { 0 };

	esp_pm_get_configuration(&pm_config);
	pm_config.light_sleep_enable = enable;

	Serial.printf("pm config: min %d max %d light sleep %d\n", pm_config.min_freq_mhz, pm_config.max_freq_mhz, pm_config.light_sleep_enable);

	ESP_ERROR_CHECK(esp_pm_configure(&pm_config));
}

void setup()
{
	Serial.begin(115200);

	init_io();

	set_leds(1);

	init_ble();

	init_display();

	set_leds(0);

	configure_light_sleep(true);
}

static int disconnectTimeout;

#define REFRESH_DELAY_MS 100

// time to wait after a device disconnected until going back to standby
// some phones kill the BT connection when the screen is off. Otherwise this
// wouldn't be needed.
#define DISCONNECT_TIMEOUT_MS (20 * 60 * 1000)

// how long the connect screen will wait for a connection
#define CONNECT_SCREEN_TIMEOUT_MS (2 * 60 * 1000)

void loop()
{
	static int i = 0;

	/* update battery voltage characteristic every 10s */
	if (!i)
		update_ble_characteristics();
	i = (++i) % 100;

	if (deviceConnected ||
	    disconnectTimeout > 0) {
		update_game_screen();
		delay(REFRESH_DELAY_MS);
		if (deviceConnected)
			disconnectTimeout = DISCONNECT_TIMEOUT_MS;
		else
			disconnectTimeout -= REFRESH_DELAY_MS;
	} else {
		show_connect_screen();
		disconnectTimeout = CONNECT_SCREEN_TIMEOUT_MS;
		while (disconnectTimeout > 0) {
			delay(REFRESH_DELAY_MS);
			disconnectTimeout -= REFRESH_DELAY_MS;

			if (deviceConnected)
				break;
		}

		if (!deviceConnected) {
			show_standby_screen();
			deinit_ble();

			// light sleep has to be turned off otherwise
			// deep sleep immediately returns for some reason
			configure_light_sleep(false);

			Serial.flush();
			Serial.end();

			enable_touch_wakeup_pin();

			esp_deep_sleep_start();
		}
	}
	return;
}

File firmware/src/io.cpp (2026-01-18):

#include <Arduino.h>
#include "driver/rtc_io.h"

#include "io.h"
#include "game_state.h"

static const int touchPins[] = { 7, 6, 5, 4 };
static const int ledPins[] = { 38, 37, 36, 35 };
static const int buttonPins[] = { 42, 41, 40, 39 };

#define WAKEUP_GPIO GPIO_NUM_3

#define BATTERY_V_PIN 14

static void set_active_player(int i, int state)
{
	if (state) {
		digitalWrite(ledPins[i], 1);
		game_state.active = i;
	} else {
		digitalWrite(ledPins[i], 0);
		game_state.active = 0xff;
	}
}

static void got_touch(void *arg)
{
	int i = (int)arg;
	int state = touchInterruptGetLastStatus(touchPins[i]);

	Serial.printf("touch %d state %d\n", i, state);
	set_active_player(i, state);
}

static void button_isr(void *arg)
{
	int i = (int)arg;
	int state = !digitalRead(buttonPins[i]);

	Serial.printf("button %d state %d\n", i, state);
	set_active_player(i, state);
}

void set_led(int led, int state)
{
	digitalWrite(ledPins[led], state);
}

void set_leds(int state)
{
	for (int i = 0; i < 4; i++)
		digitalWrite(ledPins[i], state);
}

/*
 * read the analog pin and convert the value back to the actual battery voltage.
 * (Voltage divider with 330k and 1000k resistors used)
 */
uint32_t get_battery_voltage(void)
{
	return analogReadMilliVolts(BATTERY_V_PIN) * (330 + 1000) / 330;
}

void init_io(void)
{
	int touch_threshold = 40;

	touchSetDefaultThreshold(touch_threshold);

	for (int i = 0; i < 4; i++) {
		pinMode(buttonPins[i], INPUT_PULLUP);
		touchAttachInterruptArg(touchPins[i], got_touch, (void *)i, 0);

		pinMode(ledPins[i], OUTPUT);
		digitalWrite(ledPins[i], 0);
		attachInterruptArg(buttonPins[i], button_isr, (void *)i, CHANGE);
	}

	pinMode(BATTERY_V_PIN, INPUT);

	// limit the voltage range. 4.5V battery voltage would be 1.12V on BATTERY_V_PIN
	analogSetAttenuation(ADC_6db);
}

/* set pin for bottom right corner to sleep wakeup
 * esp32-s3 seems to only support one touch wakeup pin sadly
 * having the interrupt still attached makes the wakeup not work sometimes
 */
void enable_touch_wakeup_pin(void)
{
	esp_sleep_enable_ext0_wakeup(WAKEUP_GPIO, 0);
	rtc_gpio_pulldown_dis(WAKEUP_GPIO);
	rtc_gpio_pullup_en(WAKEUP_GPIO);

	for (int i = 0; i < 4; i++)
		touchDetachInterrupt(touchPins[i]);
	touchSleepWakeUpEnable(touchPins[3], 40);
}

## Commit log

2026-01-18 add LED functions
2026-01-18 io: no more camel case functions
2026-01-18 add function to read the battery voltage
2026-01-18 ble: add battery voltage characteristic
2026-01-18 check for connected device every 100ms
2026-01-18 update battery voltage characteristic every 10s
2026-01-18 rework touch wakeup configuration
    [io.cpp, main.cpp]
2026-01-18 combine button and touch handlers
2026-01-18 add deep sleep wakeup on gpio3
    The button GPIOs arent usable for deep sleep wake up, need to rewire at
    least one of them to the until now unused GPIO3.
2026-01-18 add missing partition config
    [huge_app.csv]
2026-01-18 add stl files for the individual parts
    [battery_frame_500mah.stl, battery_frame_600mah.stl, button.stl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]
2026-01-20 add kicad files used for first production pcbs
    [C0402_L1.0-W0.5-H0.5.step, CONN-SMD_PH-2AWT.step, ESOP-8_L4.9-W3.9-H1.6-LS6.0-P1.27.step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]
2026-01-20 add production files usable for jlcpcb
    [bom.csv, designators.csv, positions.csv]
2026-01-22 initial dummy android app
    [app_bar_main.xml]
2026-01-22 app: get device addresss from app link
2026-01-27 app: settings: allow changing the server
    Add radio buttons to switch between the two currently
    supported hosts.
2026-01-29 app: suppress deprecation warnings in fallback case
2026-02-05 app: actually set correct radio button as selected
    This will need a proper implementation if there
    will be more options in the future.
2026-02-05 app: only reload webview if needed
    Always initializing the webview on onresume()
    caused some annoying delays and forwarded the user
    to the menu screen on BMC pantheon.
    Only do the init code when actually needed,
    so if either there is no current URL or
    it is different than the one from the settings.
2026-02-11 app: prototype to read battery voltage
2026-05-15 pcb: convert to newer kicad format
    [eink_mahjong_compass.kicad_sch, eink_mahjong_compass_Peripherals.kicad_sch]
2026-05-15 pcb: add locan gitignore file
2026-05-15 pcb: add missing trace to make deep sleep wakeup work
    Connect button 4 for gpio 3 as well, so it can be used to wake up the
    esp32 from deep sleep as the gpios selected for the buttons don't have
    that capability.
    In a future revision this should be redesigned so all buttons can act as
    wakeup trigger.
    [eink_mahjong_compass.kicad_pcb, eink_mahjong_compass.kicad_sch, eink_mahjong_compass_Peripherals.kicad_sch]
2026-06-20 3d: recompute
    [compass_square.FCStd]
2026-10-04 display: show battery voltage on connect screen
2026-10-04 turn on power management and light sleep
    This will reduce the power usage in theBT connected but otherwise idle
    state from 65mA to 15mA.
2026-10-04 main: move light sleep config to separate function, turn it off before deep sleep
    For some reason deep sleep doesn't work when light sleep is enabled.
    It immediately causes a reset. So turn light sleep of before entering
    deep sleep.
    [main.cpp]
2026-10-04 main: rework device timeouts
    On the connect screen there is now a 2 minute timeout until the device
    goes back to deep sleep if no client connects to it.
    After a device connected, a 20 minute timeout will start the moment the
    connection is lost. Afterwards the donnect screen will be shown.
    This was implemented because some phones disconnect the BT connection
    while their screen is off for a while. Before this would be interpreted
    as a disconnect and the connect screen would be shown.
    [main.cpp]
2026-10-04 3d: add version that is a bit flatter
    This only fits a 10mm high battery but the lower height will make it
    more usable when being placed in the middle of an auto table.
    [compass_square.FCStd]
